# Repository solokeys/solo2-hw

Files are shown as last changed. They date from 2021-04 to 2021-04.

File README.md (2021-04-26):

# Solo v2 Hardware

This repo contains the schematic and layout for Solo v2.  Specifically, it contains the Kicad source files
for the "module" PCB which contains all of the relevant circuitry.

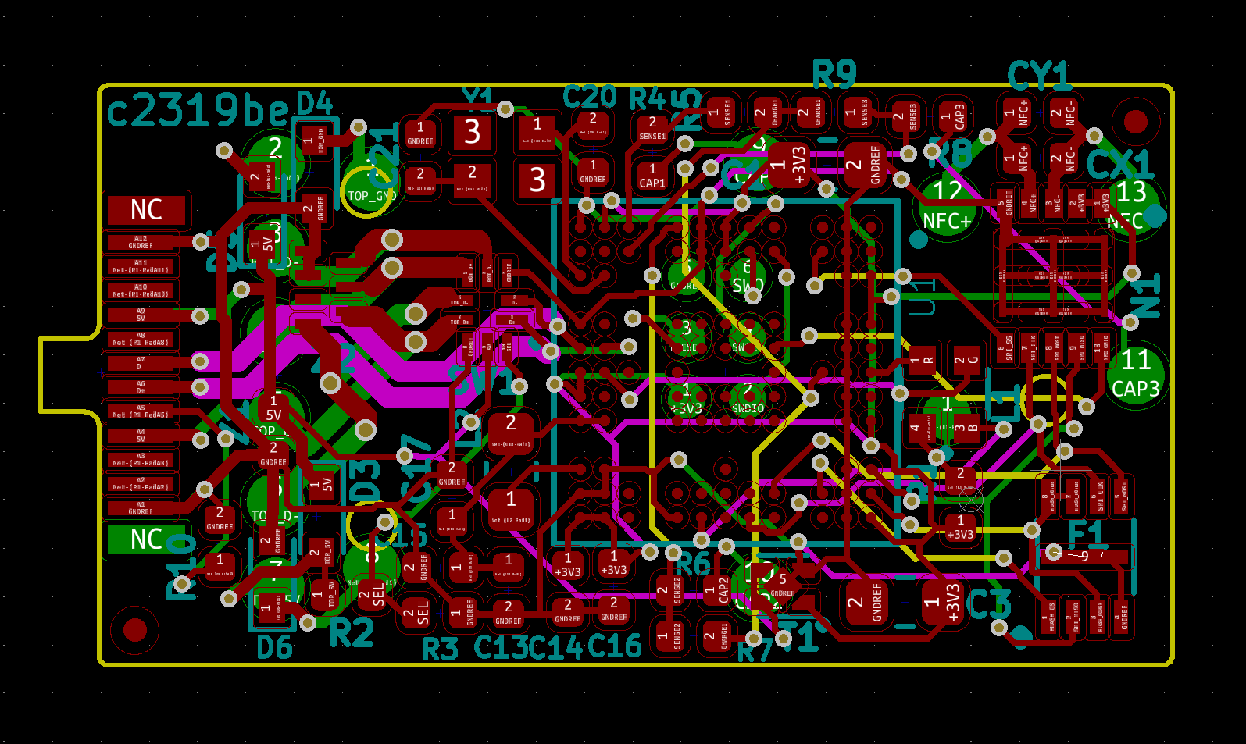
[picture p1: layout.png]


What is not included is the "cavity" PCBs, or NFC antenna.

To generate a BOM, see [`bom/`](./bom).

This is only provided as a reference.  If you'd like to submit a PR or otherwise provide feedback, please contact SoloKeys team first.

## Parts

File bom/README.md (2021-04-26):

# Generate BOM rereqs

To generate a BOM, [KiBoM](https://github.com/SchrodingersGat/KiBoM) is used.

Download KiBoM to this directory.

```
git clone https://github.com/SchrodingersGat/KiBoM
```

You then need to open the BOM plugin manager from the ("solo-A.sch") schematic in KiCad.  Plug this command in in the command field and run it.  Make sure to edit the path so that it's valid.

```
python "/Users/conor/Documents/GitHub/solo-hw/kicad/bom/KiBoM/KiBOM_CLI.py" "%I" "%O"
```

This generates an intermediate file that can then be used for generating the final BOMs.  If you change the schematic,
you will **need** to run this again.

# Generate the BOM for either USB-C or USB-A.

USB-C:
```
python3 KiBoM/KiBOM_CLI.py --cfg usbc.ini ../solo-A.xml C-BOM.csv
```

USB-A:
```
python3 KiBoM/KiBOM_CLI.py --cfg usba.ini ../solo-A.xml A-BOM.csv
```

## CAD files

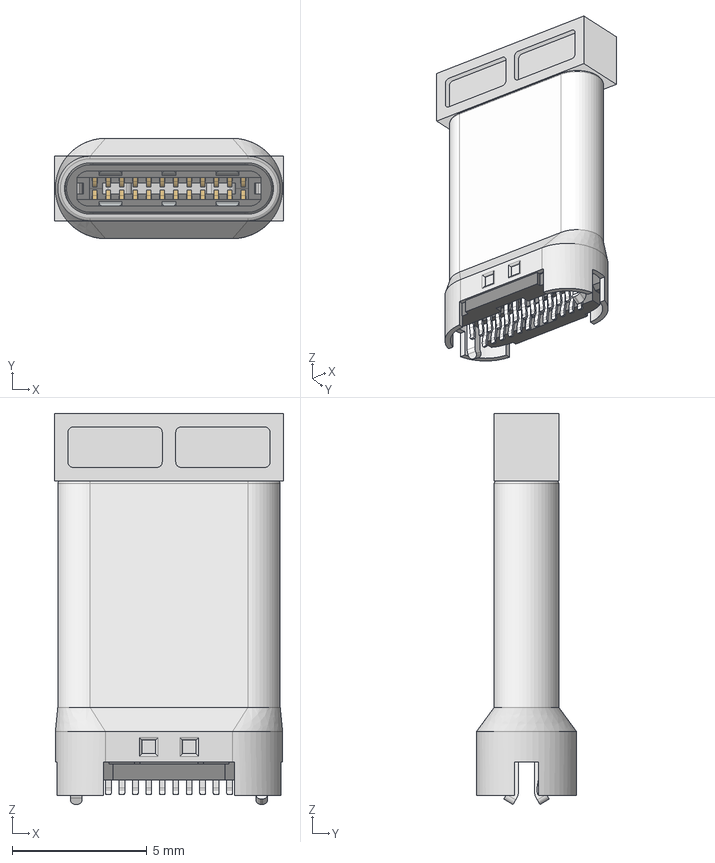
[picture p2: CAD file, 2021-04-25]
3d/wurth_632712000112_usb-c 2.step
8.50 x 3.72 x 14.5 mm
632712000112_Shelding
632712000112_Housing1
632712000112_Housing2 x 2
632712000112_Pin x 24
632712000112_Shelding2.asm x 2
632712000112_Shelding3.asm
632712000112_Mylar x 2
632712000112_Cap

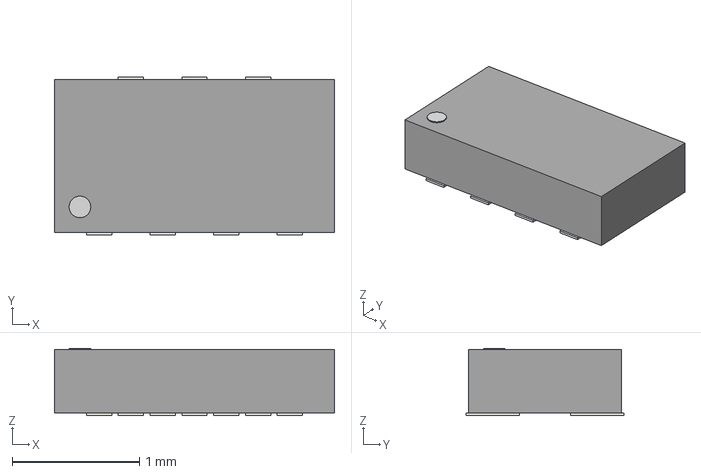
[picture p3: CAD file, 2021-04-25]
3d/PUSB3TB6AZ.step
2.20 x 1.24 x 0.53 mm

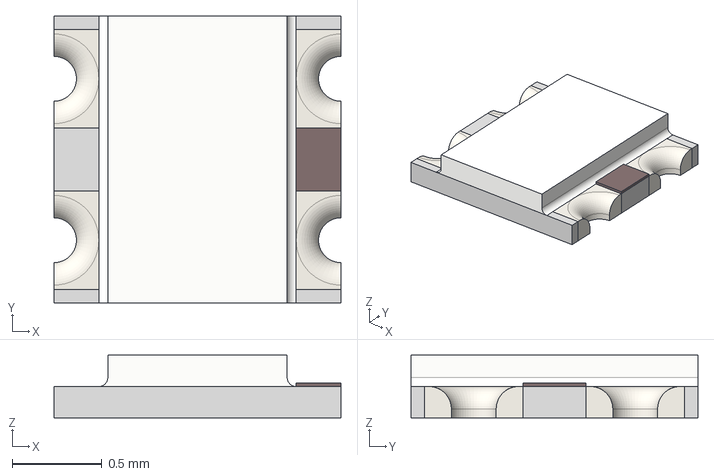
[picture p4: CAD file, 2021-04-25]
3d/EAST1616RGBB4.step
1.60 x 1.60 x 0.35 mm

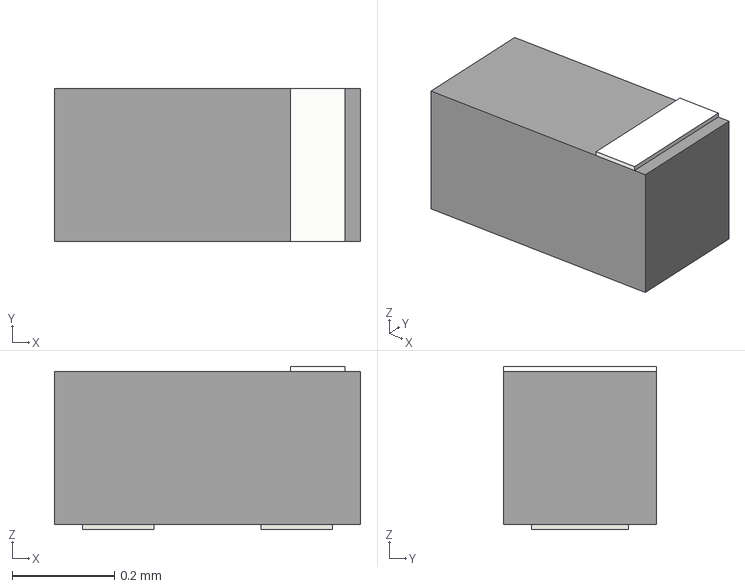
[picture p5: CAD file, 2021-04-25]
3d/ST-BAT30F4.step
0.6 x 0.3 x 0.32 mm

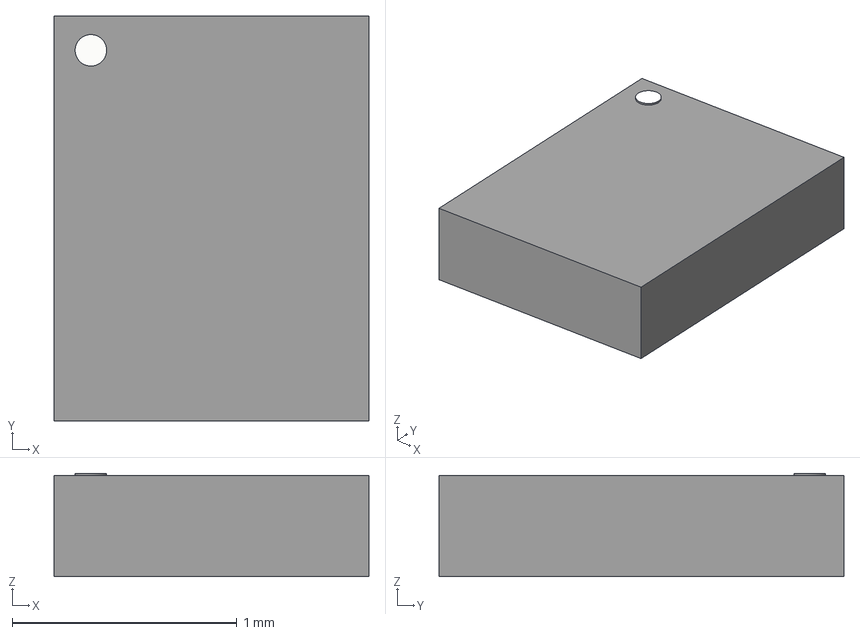
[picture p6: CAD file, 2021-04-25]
3d/FSUSB42.step
1.40 x 1.80 x 0.46 mm

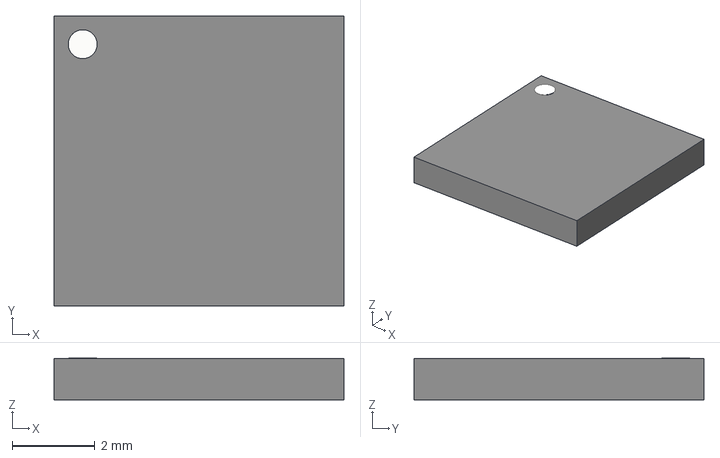
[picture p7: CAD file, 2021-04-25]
3d/lpc55.step
7.00 x 7.00 x 1.01 mm

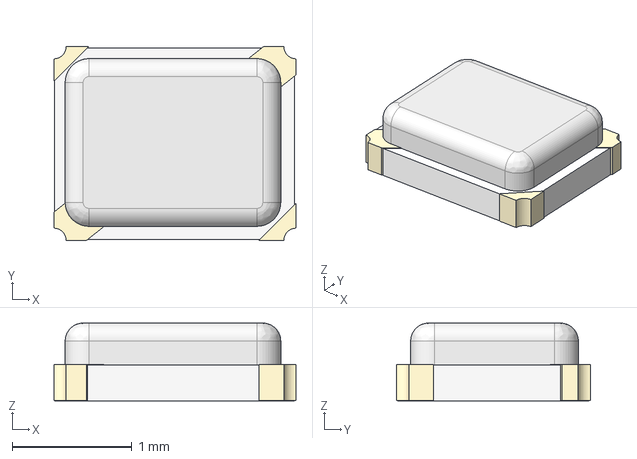
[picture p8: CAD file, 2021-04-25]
3d/XRCGB32M000F2P02R0.step
2.02 x 1.62 x 0.65 mm

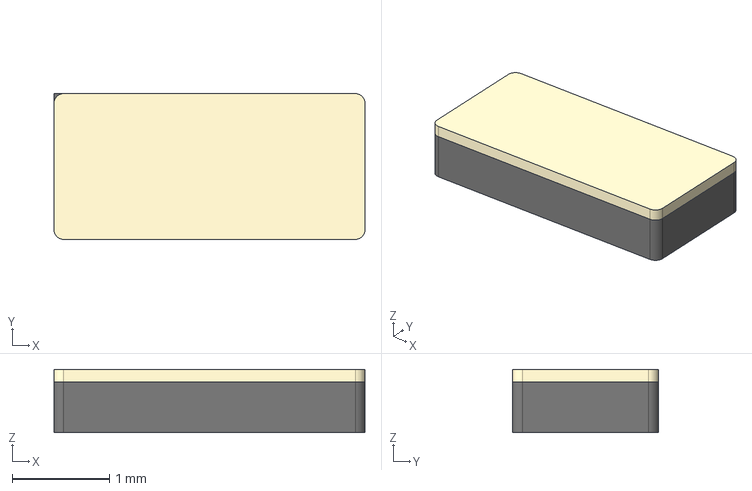
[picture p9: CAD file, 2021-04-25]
3d/CM7V-T1A-32.768KHZ-12.5PF-20PPM-TA-QC.step
3.20 x 1.50 x 0.65 mm

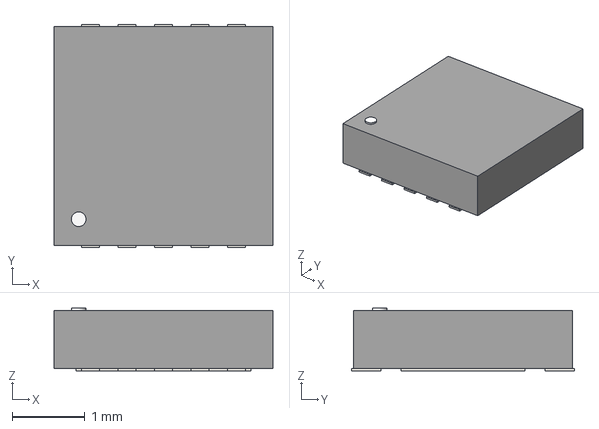
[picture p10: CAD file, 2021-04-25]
3d/MLPD3x3.step
3.00 x 3.06 x 0.86 mm

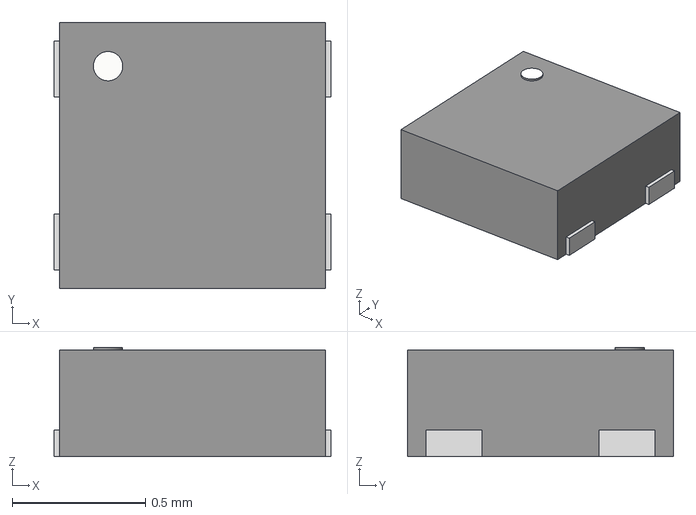
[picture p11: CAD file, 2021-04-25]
3d/tlv742p.step
1.04 x 1.00 x 0.41 mm

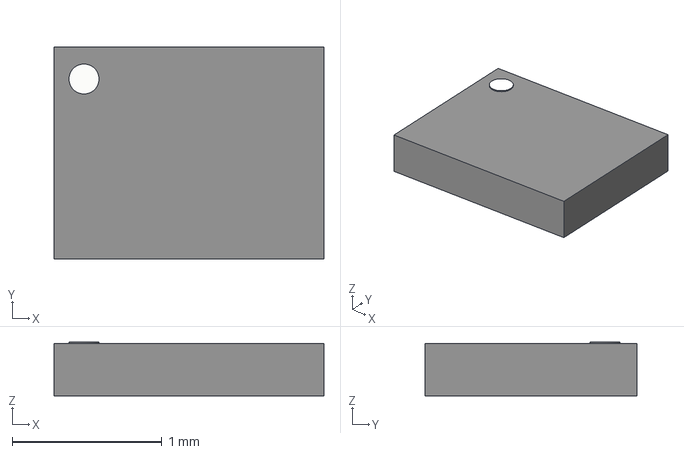
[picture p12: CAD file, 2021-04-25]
3d/AS3956-CSP.step
1.80 x 1.41 x 0.36 mm

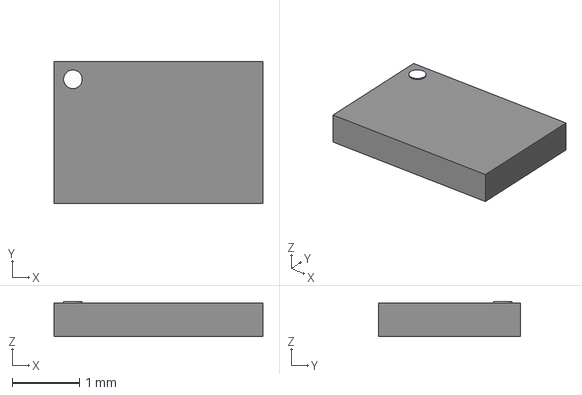
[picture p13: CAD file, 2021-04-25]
3d/USON8_2-3mm.step
3.10 x 2.10 x 0.52 mm

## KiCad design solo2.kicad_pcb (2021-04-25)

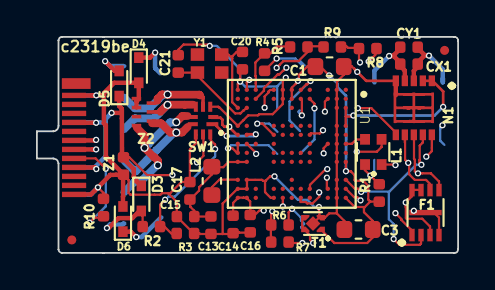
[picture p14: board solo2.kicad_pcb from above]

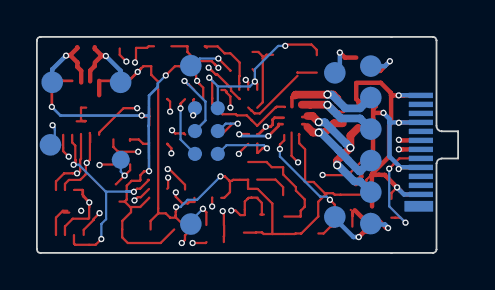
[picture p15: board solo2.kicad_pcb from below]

Board: 4 copper layers, 23.4 x 12.0 mm, 41 parts (2 on the bottom side), 43 nets.

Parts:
ABOTTOM_LEFT: Fiducial_0.5mm_Mask1mm
ATOP_RIGHT: Fiducial_0.5mm_Mask1mm
C1, C3: 22u; C_0603_1608Metric
C13, C17: 10uF; C_0402_1005Metric
C14, C15: 100nF; C_0402_1005Metric
C16: 47pF; C_0402_1005Metric
C20, C21: 8pF; C_0402_1005Metric
CX1: DNP; C_0402_1005Metric
CY1: DNP; C_0402_1005Metric
D1: ARM_DEBUG; TC2030-IDC-NL
D3, D4, D5, D6: RB521S30T5G; SOD-523-thin
F1: GD25Q16CEIGR; FLASH_2x3_USON8
L1: LED_RGBA; RGB_LED_606
L2: 4u7H; L_0603_1608Metric
N1: FM11NC08; MLPD3X3
P1: USB_C_Plug; USB-C_WURTH
R1: 180R; R_0402_1005Metric
R2, R10: 5k; R_0402_1005Metric
R3: 40k; R_0402_1005Metric
R4, R6, R8: 10k; R_0402_1005Metric
R5, R7, R9: 500k; R_0402_1005Metric
SW1: FSUSB42
T1: TLV742p; Texas_X2SON-4_1x1mm_P0.65mm
TOP1: TOP_A; top-A
TP1: TestPoint; TestPoint_Pad_D1.0mm
U1: LPC55S69JEV98K; BGA98C50P13X13_700X700X97N
Y1: XRCGB16M000FXN01R0; Crystal-2mmx1.6mm
Z1: GG040205100N2P; R_0402_1005Metric
Z2: PUSB3TB6AZ; XSON7

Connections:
+3V3: C1.1, C3.1, C14.1, C16.1, D1.1, N1.1, N1.2, R1.1, T1.1, U1.A3, U1.A5, U1.A9, U1.A13, U1.G1, U1.G2, U1.M1, U1.M13, U1.N7, U1.N8, U1.N13
/5V: D3.1, D5.1, P1.A4, P1.A9, P1.B4, P1.B9, SW1.9, T1.3, T1.4, Z1.1
/BOT_D+: SW1.5, TOP1.4, Z2.6
/BOT_D-: SW1.4, TOP1.3, Z2.5
/CAP1: R4.1, TOP1.9
/CAP2: R6.1, TOP1.10
/CAP3: R8.1, TOP1.11
/D+: P1.A6, SW1.1, U1.M6
/D-: P1.A7, SW1.2, U1.N6
/NFC+: CX1.1, CY1.1, N1.4, TOP1.12
/NFC-: CX1.2, CY1.2, N1.3, TOP1.13
/SEL: R2.2, R3.2, SW1.10
/TOP_5V: D3.2, R2.1, TOP1.7
/TOP_D+: SW1.7, TOP1.5, Z2.7
/TOP_D-: SW1.6, TOP1.6, Z2.4
/TOP_GND: D4.1, TOP1.1
/solo/FLASH_CS: F1.1, U1.C12
/solo/FLASH_POWER: F1.3, F1.7, F1.8, U1.A12
/solo/Sheet5DDC9C58/B: L1.3, U1.H13
/solo/Sheet5DDC9C58/CHARGE1: R5.2, R7.2, R9.2, U1.C7
/solo/Sheet5DDC9C58/G: L1.2, U1.M7
/solo/Sheet5DDC9C58/NFC_GPIO: N1.10, U1.E6
/solo/Sheet5DDC9C58/R: L1.1, U1.A7
/solo/Sheet5DDC9C58/SENSE1: R4.2, R5.1, U1.L1
/solo/Sheet5DDC9C58/SENSE2: R6.2, R7.1, U1.J1
/solo/Sheet5DDC9C58/SENSE3: R8.2, R9.1, U1.L2
/solo/Sheet5DDC9C58/SPI_CLK: F1.6, N1.7, U1.F13
/solo/Sheet5DDC9C58/SPI_MISO: F1.2, N1.9, U1.A11
/solo/Sheet5DDC9C58/SPI_MOSI: F1.5, N1.8, U1.E12
/solo/Sheet5DDC9C58/SPI_SS: N1.6, U1.C2
/solo/Sheet5DDC9C58/SWCLK: D1.4, U1.F1
/solo/Sheet5DDC9C58/SWDIO: D1.2, U1.E2
/solo/Sheet5DDC9C58/SWO: D1.6, U1.F2
/solo/nRESET: D1.3, U1.J6
GNDREF: C1.2, C3.2, C13.2, C14.2, C15.2, C16.2, C17.2, C20.1, C21.1, D1.5, D4.2, D6.2, F1.4, N1.5, N1.EXP, P1.A1, P1.A12, P1.B1, P1.B12, R3.1, R10.2, SW1.3, SW1.8, T1.2, T1.5, U1.B1, U1.B2, U1.B3, U1.B5, U1.B6, U1.B7, U1.B8, U1.B9, U1.B11, U1.B12, U1.B13, U1.H1, U1.H2, U1.J13, U1.M11, U1.M12, U1.N1, U1.N5, U1.N12, Z1.2, Z2.1, Z2.2
unnamed: C13.1, C15.1, C17.1, L2.2, U1.M9, U1.N9
unnamed: C20.2, U1.N3, Y1.1
unnamed: C21.2, U1.M3, Y1.2
unnamed: D5.2, TOP1.2
unnamed: D6.1, TOP1.8
unnamed: L1.4, R1.2, TP1.1
unnamed: L2.1, U1.N11
unnamed: P1.A5, R10.1

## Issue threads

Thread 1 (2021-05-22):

Main schematic solo.sch missing

dbeinder, 2021-05-22:
The hierarchical sheet solo.sch is missing from the repo

conorpp, 2021-05-27:
Doh!  just added them, thanks for reporting.

Closed 2021-05-27.

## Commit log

2021-04-26 readme, bom
2021-05-27 add missing schematics and rename
    [LPC55Sxx.sch, module.sch, solo2.sch]
